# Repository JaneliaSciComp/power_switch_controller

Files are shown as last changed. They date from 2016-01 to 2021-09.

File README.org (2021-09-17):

# Created 2018-07-11 Wed 15:28
#+OPTIONS: title:nil author:nil email:nil toc:t |:t ^:nil
#+OPTIONS: title:nil author:nil email:nil toc:t |:t ^:nil
#+EXPORT_FILE_NAME: README
* Repository Information

- Name :: power_switch_controller
- Version :: 1.0
- License :: BSD, Open-Source Hardware
- URL :: https://github.com/janelia-modular-devices/power_switch_controller.git
- Author :: Peter Polidoro
- Email :: peter@polidoro.io

** Description

This device controls low-side power switches for turning on and off solenoids,
relays, and resistive loads.

* Images

* Usage Instructions

- Connect a power supply to the power switch controller board.
- Connect devices to be switched to the shrouded header connectors on the
  board with either ribbon cables and IDC connectors or individual 2-pin
  connectors.
- Connect USB cable to from device to host machine and control over a serial
  port.

* Build Instructions

- This controller is made from a single 5x3 or 3x2 form factor modular device.
- This device consists of two pcbs, either the (modular_device_base_5x3) and the
  (power_switch_controller_5x3), or the (modular_device_base_3x2) and the
  (power_switch_controller_3x2).
- In addition to the two pcbs, there is one acrylic mounting plate
  (modular_device_enclosure 5x3 enclosure_bottom) or (modular_device_enclosure
  3x2 enclosure_bottom).
- Send the zip files containing the gerbers for each of the two pcbs to your
  favorite pcb manufacturer for fabrication.
- Using the bill of materials and vendor parts lists order the parts necessary
  for construction for the two pcbs and the mounting plate.
- Assemble each of the pcbs using the assembly instructions provided for each.
- Use the dxf file for the enclosure_bottom to cut the mounting plate from the
  acrylic sheet using a laser cutter or send the dxf to a laser cutting
  service for fabrication.

* Hardware

** power_switch_controller_3x2

*** Repository Information

- Name :: power_switch_controller_3x2
- Version :: 1.1
- License :: Open-Source Hardware
- URL :: https://github.com/janelia-kicad/power_switch_controller_3x2
- Author :: Peter Polidoro
- Email :: peter@polidoro.io

**** Description

This board controls up to 8 low-side power switches for turning on and off
solenoids, relays, and resistive loads.

*** Images

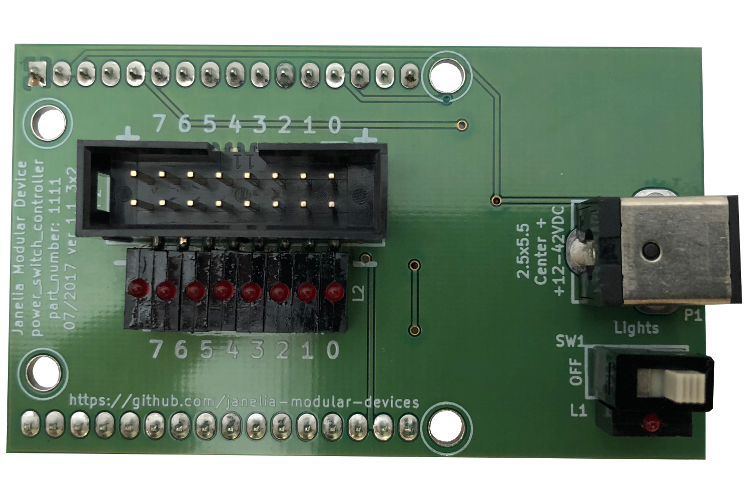
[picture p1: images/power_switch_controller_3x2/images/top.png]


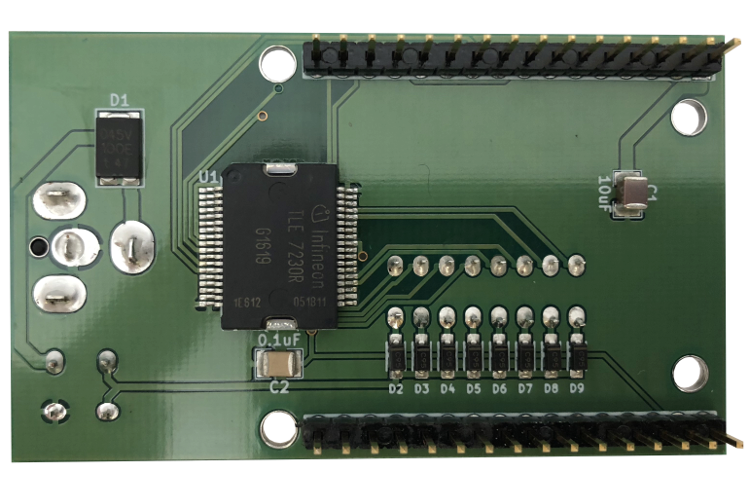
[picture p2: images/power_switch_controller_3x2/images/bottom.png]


*** Schematic

[[file:./hardware/power_switch_controller_3x2/schematic/power_switch_controller_3x2.pdf][./hardware/power_switch_controller_3x2/schematic/power_switch_controller_3x2.pdf]]

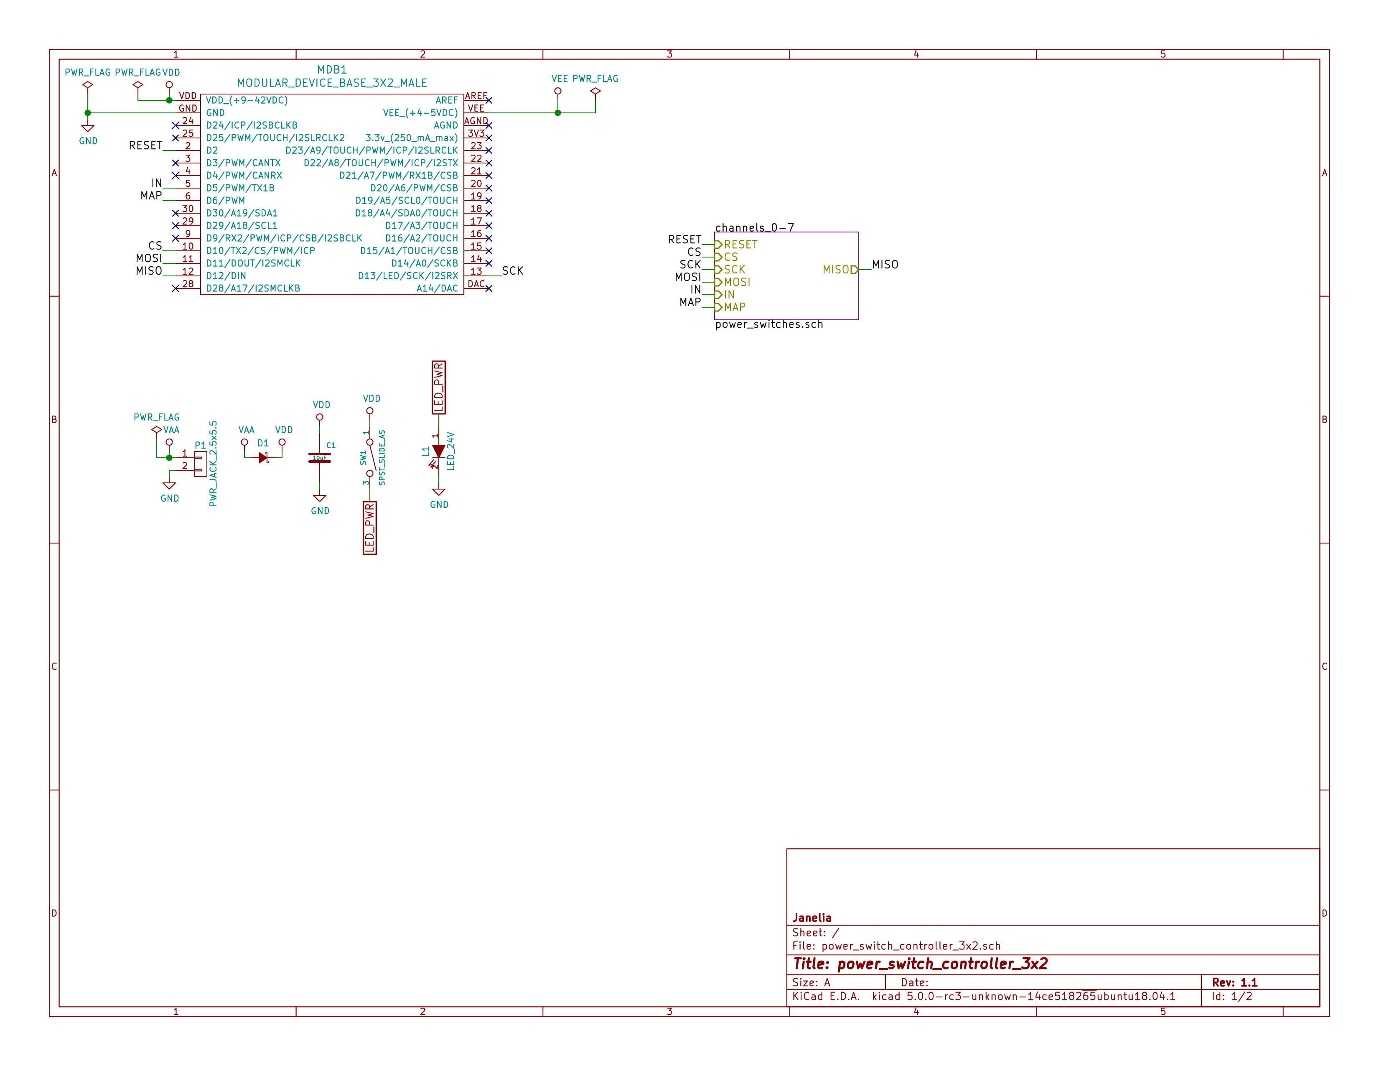
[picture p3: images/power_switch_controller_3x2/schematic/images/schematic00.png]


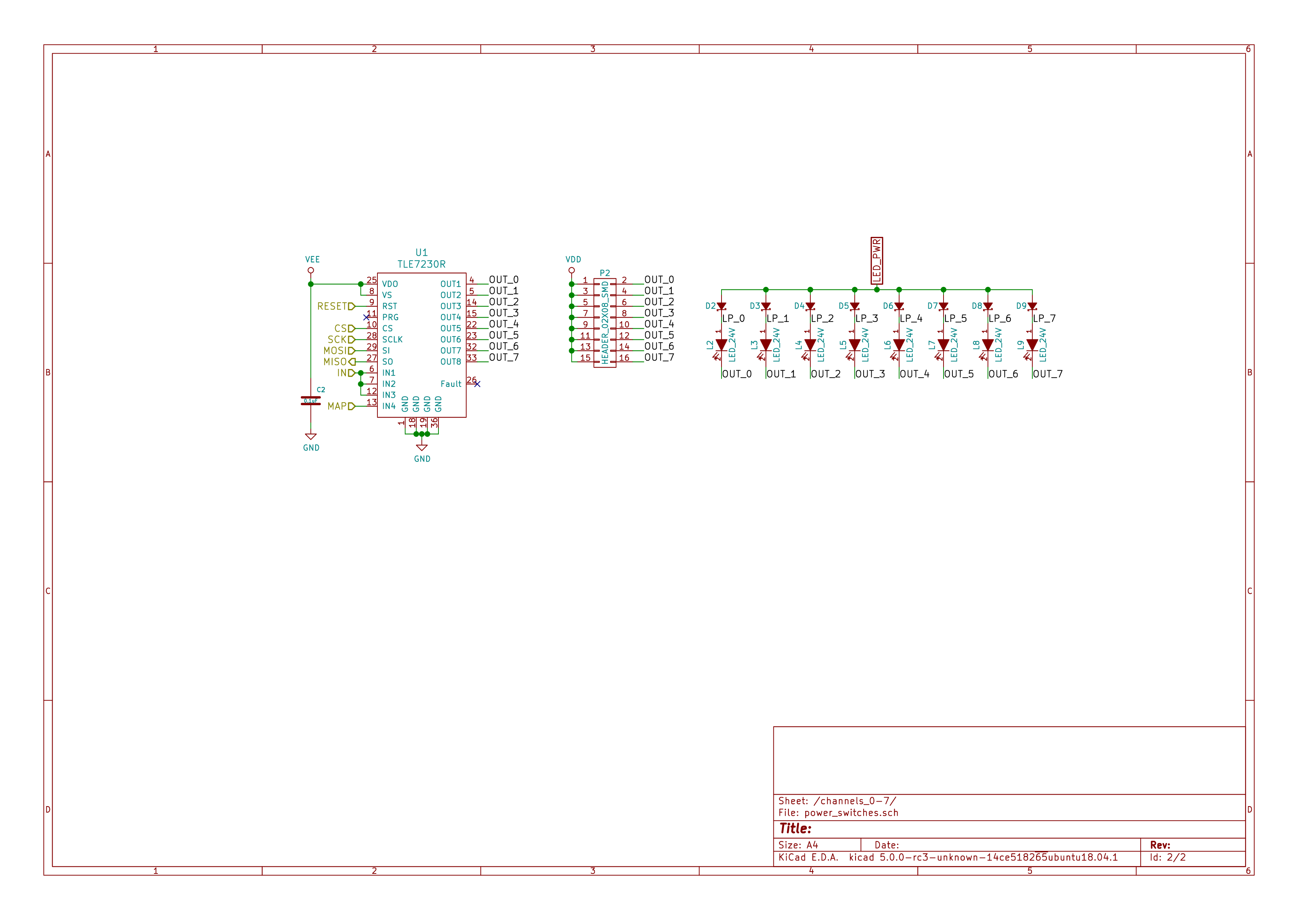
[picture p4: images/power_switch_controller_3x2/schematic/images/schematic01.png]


*** Gerbers

Send gerbers zip file to your favorite PCB manufacturer for fabrication.

[[file:./hardware/power_switch_controller_3x2/gerbers/power_switch_controller_5x3_v1.1.zip][./hardware/power_switch_controller_3x2/gerbers/power_switch_controller_5x3_v1.1.zip]]

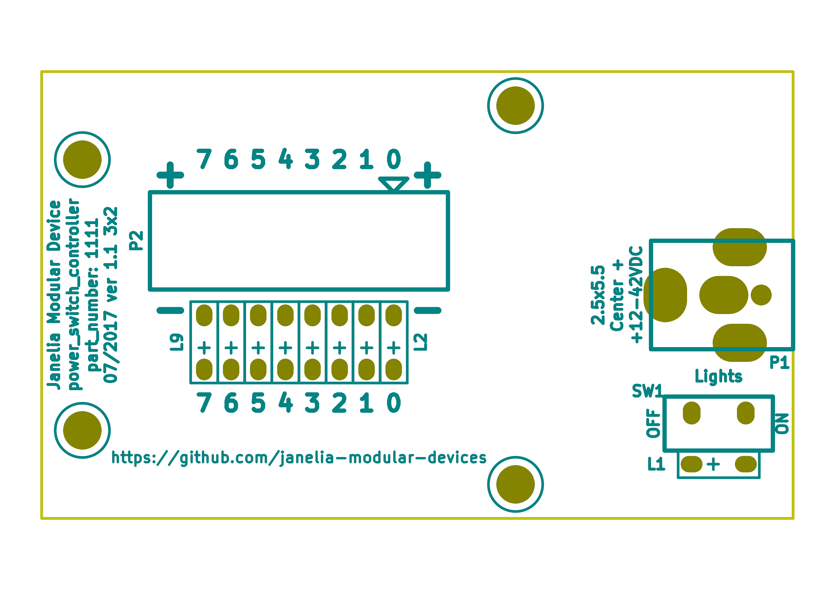
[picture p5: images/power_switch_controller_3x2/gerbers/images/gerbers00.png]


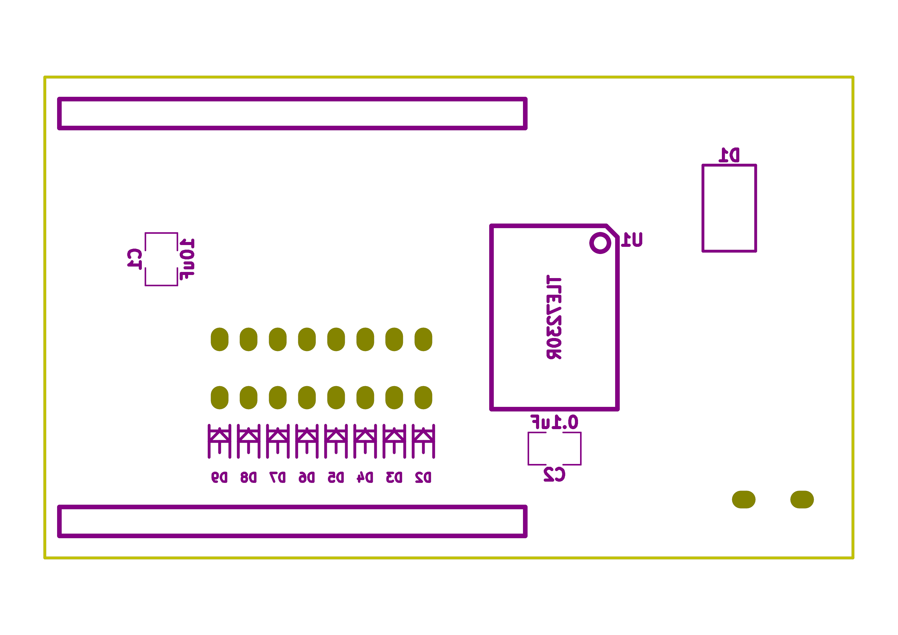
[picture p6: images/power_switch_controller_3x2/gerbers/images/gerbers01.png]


*** Bill of Materials

**** PCB Parts

| Item | Reference(s)               | Quantity | PartNumber     | Vendor  | Description                               |
|------+----------------------------+----------+----------------+---------+-------------------------------------------|
|    1 | C1                         |        1 | 445-4536-1-ND  | digikey | CAP CER 10UF 50V 10% X7S 1210             |
|    2 | C2                         |        1 | 399-13229-1-ND | digikey | CAP CER 0.1UF 100V X7R 1210               |
|    3 | D1                         |        1 | 568-11697-1-ND | digikey | DIODE SCHOTTKY 45V 10A CFP15              |
|    4 | D2 D3 D4 D5 D6 D7 D8 D9    |        8 | CMHD3595 CT-ND | digikey | DIODE GEN PURP 150V 150MA SOD123          |
|    5 | L1 L2 L3 L4 L5 L6 L7 L8 L9 |        9 | 350-1723-ND    | digikey | LED 2MM 24V VERTICAL RED PC MNT           |
|    6 | MDB1                       |        2 | S1011E-16-ND   | digikey | 16 Position Header Through Hole Male Pins |
|    7 | P1                         |        1 | CP-063BH-ND    | digikey | CONN PWR JACK DC 2.5X5.5 8A T/H           |
|    8 | P2                         |        1 | S9187-ND       | digikey | CONN HEADR 2.54MM 16POS GOLD SMD          |
|    9 | SW1                        |        1 | 360-2610-ND    | digikey | SWITCH SLIDE SPST 0.4VA 28V               |
|   10 | U1                         |        1 | TLE7230RCT-ND  | digikey | IC SW SMART OCTAL LOWSIDE PDSO36          |

**** Supplemental Parts

| Item | Quantity | PartNumber   | Vendor  | Description                       |
|------+----------+--------------+---------+-----------------------------------|
|    1 |       32 | WM2800-ND    | digikey | CONN HOUSING 2POS .100 SINGLE     |
|    2 |       64 | WM2512-ND    | digikey | CONN TERM FEMALE 22-24AWG GOLD    |
|    3 |       64 | WM2513-ND    | digikey | CONN TERM FEMALE 24-30AWG GOLD    |
|    4 |        4 | AKC16H-ND    | digikey | CONN IDC SKT 16POS W/POL 15 GOLD  |
|    5 |        1 | MC16M-300-ND | digikey | CBL RIBN 16COND 0.050 MULTI 300ft |
|    6 |        4 | APK16B-ND    | digikey | CONN IDC PIN 16POS 30AU NO LATCH  |
|    7 |       32 | WM2900-ND    | digikey | CONN HOUSING 2POS .100 W/LATCH    |
|    8 |       64 | WM2570-ND    | digikey | CONN TERM FEMALE 22-24AWG GOLD    |
|    9 |       64 | WM2572-ND    | digikey | CONN SOCKET 24-30AWG CRIMP 30AU   |
|   10 |       32 | WM2533-ND    | digikey | CONN HOUSING MALE 2POS .100       |
|   11 |       64 | WM2566-ND    | digikey | CONN PIN 24-30AWG CRIMP 30GOLD    |
|   12 |       64 | WM2567-ND    | digikey | CONN TERM MALE 22-24AWG GOLD      |

**** Vendor Parts Lists

[[file:./hardware/power_switch_controller_3x2/bom/digikey_parts.csv][./hardware/power_switch_controller_3x2/bom/digikey_parts.csv]]

[[file:./hardware/power_switch_controller_3x2/bom/supplemental_digikey_parts.csv][./hardware/power_switch_controller_3x2/bom/supplemental_digikey_parts.csv]]

*** Supplemental Documentation

**** Assembly Instructions

- Solder header pins into the driver board, making note of TOP label.
  Insert header pins on bottom of board so that the long unsoldered header
  pins point down when the TOP label faces up.
- Solder surface mount and through hole components onto the pcb.

** power_switch_controller_5x3

*** Repository Information
- Author :: Peter Polidoro
- License :: Open-Source Hardware

* Firmware

** PowerSwitchController

*** Library Information
- Name :: PowerSwitchController
- Version :: 2.1.3
- License :: BSD
- URL :: https://github.com/janelia-arduino/PowerSwitchController
- Author :: Peter Polidoro
- Email :: peter@polidoro.io

**** Description

Modular device power switch controller library.

*** API NAMES

#+BEGIN_SRC js
  {
    "id": "getApi",
    "result": {
      "firmware": [
        "PowerSwitchController"
      ],
      "verbosity": "NAMES",
      "functions": [
        "setChannelOn",
        "setChannelOff",
        "setChannelsOn",
        "setChannelsOff",
        "toggleChannel",
        "toggleChannels",
        "toggleAllChannels",
        "setAllChannelsOn",
        "setAllChannelsOff",
        "setChannelOnAllOthersOff",
        "setChannelOffAllOthersOn",
        "setChannelsOnAllOthersOff",
        "setChannelsOffAllOthersOn",
        "getChannelsOn",
        "getChannelsOff",
        "getChannelCount",
        "saveState",
        "recallState",
        "addPwm",
        "startPwm",
        "stopPwm",
        "stopAllPwm",
        "setPower",
        "getPowers"
      ],
      "parameters": [
        "channel",
        "channels",
        "state",
        "delay",
        "period",
        "on_duration",
        "count",
        "pwm_index",
        "channel_group",
        "power"
      ],
      "properties": [
        "states"
      ]
    }
  }
#+END_SRC

*** API GENERAL

[[file:./firmware/PowerSwitchController/api/]]

*** Ancestors

[[https://github.com/janelia-arduino/ModularServer]]

[[https://github.com/janelia-arduino/ModularDeviceBase]]

*** Clients

*** Devices

[[https://github.com/janelia-modular-devices/modular_device_base.git]]

[[https://github.com/janelia-modular-devices/power_switch_controller.git]]

*** More Detailed Modular Device Information

[[https://github.com/janelia-modular-devices/modular-devices]]

*** Installation Instructions

[[https://github.com/janelia-arduino/arduino-libraries]]

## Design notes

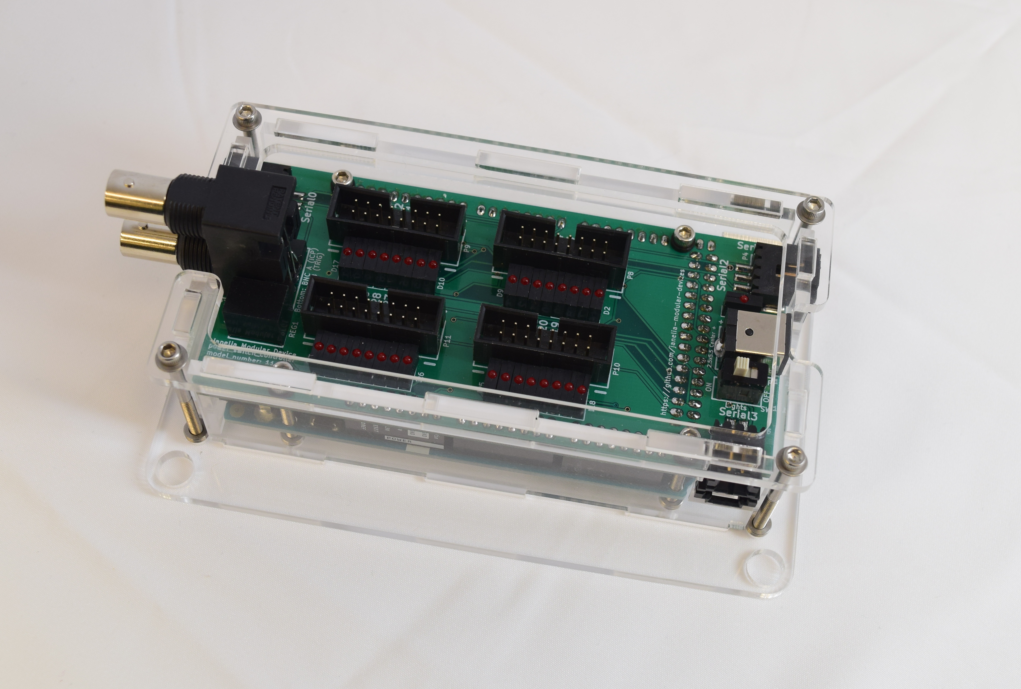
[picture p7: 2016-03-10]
images/power_switch_controller_01.jpg

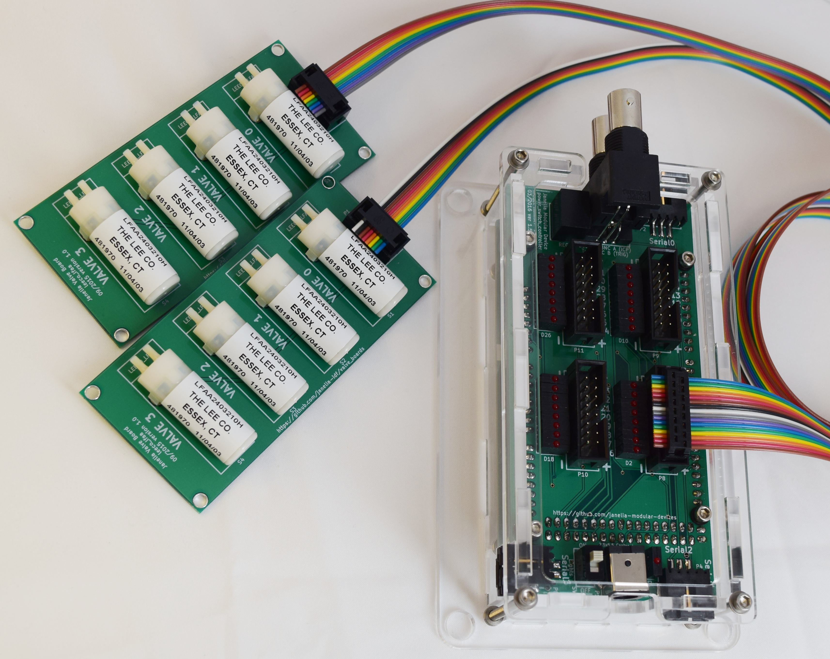
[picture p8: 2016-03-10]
images/power_switch_controller_02.jpg

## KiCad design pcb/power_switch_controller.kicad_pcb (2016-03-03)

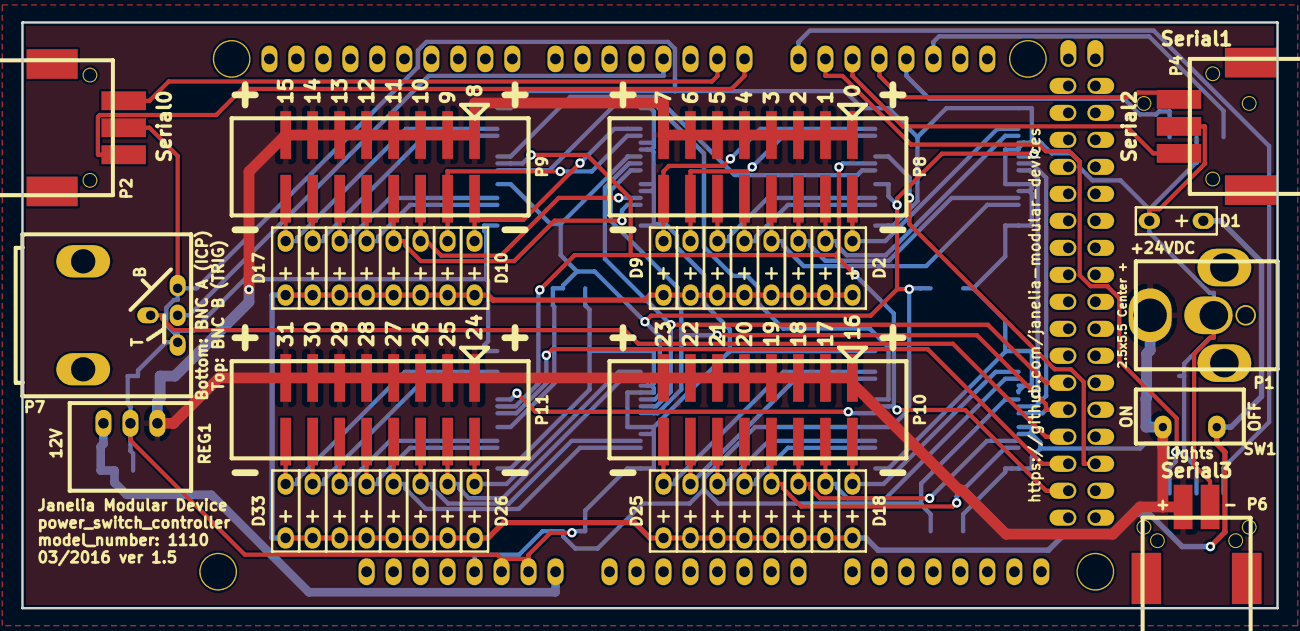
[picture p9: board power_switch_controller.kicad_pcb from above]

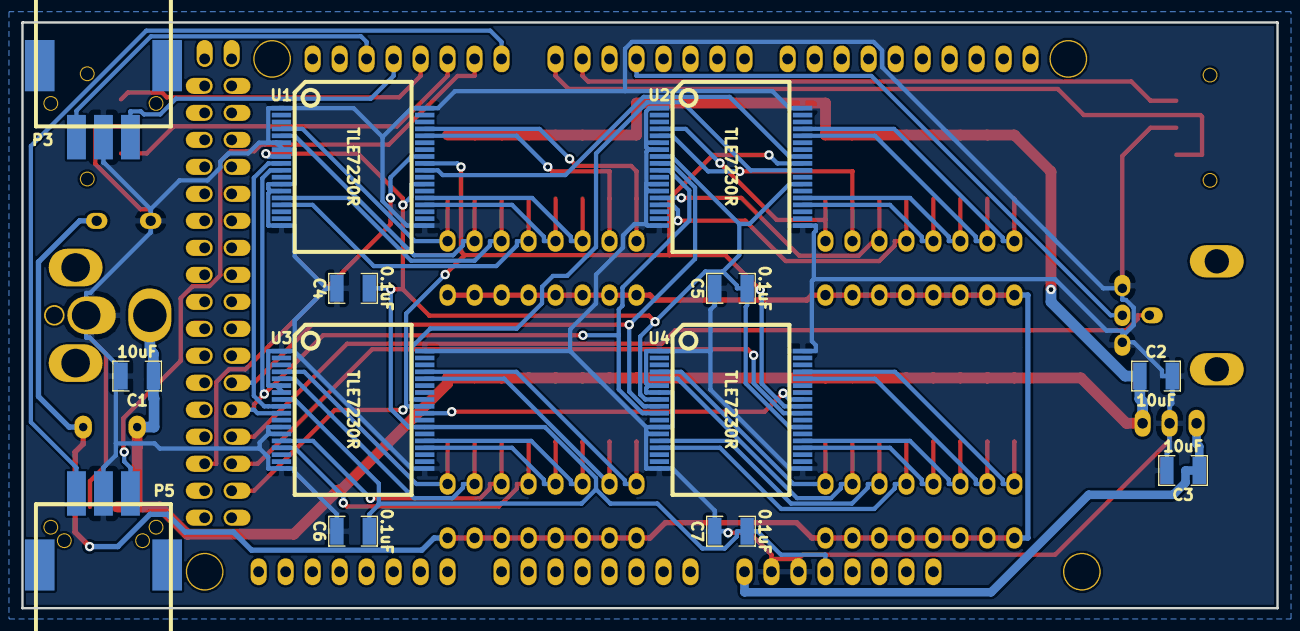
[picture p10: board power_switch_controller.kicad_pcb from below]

Board: 2 copper layers, 118.1 x 55.1 mm, 58 parts (13 on the bottom side), 55 nets.

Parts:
ARDUINO1: ARDUINO_MEGA; ARDUINO_MEGA_SHIELD
C1, C2, C3: 10uF; SM1210
C4, C5, C6, C7: 0.1uF; SM1210
D1, D2, D3, D4, D5, D6, D7, D8, D9, D10, D11, D12, D13, D14, D15, D16, D17, D18, D19, D20, D21, D22, D23, D24, D25, D26, D27, D28, D29, D30, D31, D32, D33: LED_24V; LED_555-3XXX
P1: PWR_JACK_2.5x5.5; DCJACK_2PIN_HIGHCURRENT
P2, P3, P4, P5: HEADER_01X03_SMD_RA; Header_3_Pin_SMD_RA
P6: HEADER_01X02_SMD_RA; Header_2_Pin_SMD_RA
P7: BNC_DOUBLE_RA; BNC_DOUBLE
P8, P9, P10, P11: HEADER_02X08_SMD; HEADER_02x08_SMD
REG1: CONV_DC_DC_12V_1A; DC_DC_CONV_R78C
SW1: SPST_SLIDE_AS
U1, U2, U3, U4: TLE7230R; PG-DSO-36

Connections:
+5V: ARDUINO1.5V_1, C4.1, C5.1, C6.1, C7.1, U1.8, U1.25, U2.8, U2.25, U3.8, U3.25, U4.8, U4.25
/BNC_A: ARDUINO1.48, P7.1
/BNC_B: ARDUINO1.3, P7.3
/CS: ARDUINO1.46, U1.10, U2.10, U3.10, U4.10
/LED_PWR: D1.1, D2.1, D3.1, D4.1, D5.1, D6.1, D7.1, D8.1, D9.1, D10.1, D11.1, D12.1, D13.1, D14.1, D15.1, D16.1, D17.1, D18.1, D19.1, D20.1, D21.1, D22.1, D23.1, D24.1, D25.1, D26.1, D27.1, D28.1, D29.1, D30.1, D31.1, D32.1, D33.1, SW1.3
/MISO: ARDUINO1.50, U4.27
/MOSI: ARDUINO1.51, U1.29
/OUT0: D2.2, P8.2, U1.4
/OUT1: D3.2, P8.4, U1.5
/OUT2: D4.2, P8.6, U1.14
/OUT3: D5.2, P8.8, U1.15
/OUT4: D6.2, P8.10, U1.22
/OUT5: D7.2, P8.12, U1.23
/OUT6: D8.2, P8.14, U1.32
/OUT7: D9.2, P8.16, U1.33
/OUT8: D10.2, P9.2, U2.4
/OUT9: D11.2, P9.4, U2.5
/OUT10: D12.2, P9.6, U2.14
/OUT11: D13.2, P9.8, U2.15
/OUT12: D14.2, P9.10, U2.22
/OUT13: D15.2, P9.12, U2.23
/OUT14: D16.2, P9.14, U2.32
/OUT15: D17.2, P9.16, U2.33
/OUT16: D18.2, P10.2, U3.4
/OUT17: D19.2, P10.4, U3.5
/OUT18: D20.2, P10.6, U3.14
/OUT19: D21.2, P10.8, U3.15
/OUT20: D22.2, P10.10, U3.22
/OUT21: D23.2, P10.12, U3.23
/OUT22: D24.2, P10.14, U3.32
/OUT23: D25.2, P10.16, U3.33
/OUT24: D26.2, P11.2, U4.4
/OUT25: D27.2, P11.4, U4.5
/OUT26: D28.2, P11.6, U4.14
/OUT27: D29.2, P11.8, U4.15
/OUT28: D30.2, P11.10, U4.22
/OUT29: D31.2, P11.12, U4.23
/OUT30: D32.2, P11.14, U4.32
/OUT31: D33.2, P11.16, U4.33
/RESET: ARDUINO1.44, U1.9, U2.9, U3.9, U4.9
/RX0: ARDUINO1.0, P2.1
/RX1: ARDUINO1.19, P3.1
/RX2: ARDUINO1.17, P4.1
/RX3: ARDUINO1.15, P5.1
/SCK: ARDUINO1.52, U1.28, U2.28, U3.28, U4.28
/SO1: U1.27, U2.29
/SO2: U2.27, U3.29
/SO3: U3.27, U4.29
/TX0: ARDUINO1.1, P2.3
/TX1: ARDUINO1.18, P3.3
/TX2: ARDUINO1.16, P4.3
/TX3: ARDUINO1.14, P5.3
/V_IN: ARDUINO1.V_IN, C3.1, REG1.3
GND: ARDUINO1.GND1, ARDUINO1.GND2, C1.2, C2.2, C3.2, C4.2, C5.2, C6.2, C7.2, D1.2, P1.2, P2.2, P3.2, P4.2, P5.2, P6.1, P7.2, P7.4, REG1.2, U1.1, U1.6, U1.7, U1.12, U1.13, U1.18, U1.19, U1.36, U2.1, U2.6, U2.7, U2.12, U2.13, U2.18, U2.19, U2.36, U3.1, U3.6, U3.7, U3.12, U3.13, U3.18, U3.19, U3.36, U4.1, U4.6, U4.7, U4.12, U4.13, U4.18, U4.19, U4.36
VAA: C1.1, C2.1, P1.1, P6.2, P8.1, P8.3, P8.5, P8.7, P8.9, P8.11, P8.13, P8.15, P9.1, P9.3, P9.5, P9.7, P9.9, P9.11, P9.13, P9.15, P10.1, P10.3, P10.5, P10.7, P10.9, P10.11, P10.13, P10.15, P11.1, P11.3, P11.5, P11.7, P11.9, P11.11, P11.13, P11.15, REG1.1, SW1.1

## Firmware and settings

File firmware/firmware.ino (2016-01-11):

// power_switch_controller
#include "Flash.h"
#include <EEPROM.h>
#include "Streaming.h"
#include "ArduinoJson.h"
#include "JsonSanitizer.h"
#include "JsonStream.h"
#include "Array.h"
#include "Vector.h"
#include "MemoryFree.h"
#include "ConstantVariable.h"
#include "SavedVariable.h"
#include "BetterMap.h"
#include "ModularServer.h"
#include "NewhavenDisplay.h"
#include "Encoder.h"
#include "StandaloneInterface.h"
#include "EventController.h"
#include "Constants.h"
#include "Callbacks.h"
#include "Controller.h"

#include "SPI.h"
#include "PowerSwitch.h"
#include "IndexedContainer.h"


// See README.md for more information

void setup()
{
  controller.setup();
}

void loop()
{
  controller.update();
}

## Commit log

2014-11-25 Pcb file setup.
    [power_switch_controller.sch]
2014-12-12 Initial design setup.
    [bom_pcb_add.csv, digikey_order_pcb_add.csv, power_switch_controller.dsn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]
2015-01-05 Made design changes preparing for version 1.0.
    [power_switch_controller.dsn, power_switch_controller.kicad_pcb, power_switch_controller.sch]
2015-01-06 Changed connectors to 2x16 header.
    [power_switch_controller.kicad_pcb, power_switch_controller.sch]
2015-01-08 Moved components on pcb.
    [power_switch_controller.dsn, power_switch_controller.kicad_pcb, power_switch_controller.sch]
2015-01-08 Finished pcb version 1.0
    [bom_pcb.csv, bom_pcb_add.csv, digikey_order.csv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]
2015-01-09 Added schematic pdf.
2015-01-09 Added schematic svg.
2015-01-16 Progress on firmware for pcb v1.0.
2015-01-20 Progress towards 32 power switches.
    [power_switch_controller.kicad_pcb, power_switch_controller.sch]
2015-01-21 Finished pcb v1.1.
    [bom_pcb.csv, bom_pcb_add.csv, digikey_order.csv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]
2015-01-28 remote -> modular.
    [power_switch_controller.kicad_pcb]
2015-02-06 Moved modular_device setup into power_switch_controller.
2015-02-13 Added more StandAlone frames.
2015-02-18 pcb v1.2.
    [power_switch_controller.dsn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]
2015-03-19 StandardCplusplus -> array. Updated pin constants.
2015-04-18 Added new frames.
2015-04-22 Added spikeHold standalone frame.
2015-04-22 Partially updated pwm frame.
2015-04-22 Finished pwm standalone frame.
2015-07-13 JaneliaSciComp -> janelia-modular-devices.
    [power_switch_controller.kicad_pcb]
2015-08-10 SPST switch -> DPST switch.
    [bom_pcb.csv, bom_pcb_add.csv, digikey_order_pcb.csv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]
2015-08-10 Updated digikey_order_add.
    [digikey_order_pcb_add.csv, power_switch_controller.kicad_pcb]
2015-09-09 led_pwr_pin -> lights_pin.
2015-09-09 Kicad update.
    [power_switch_controller.sch]
2015-10-02 New digikey order for multiple modular devices.
    [digikey_order.csv]
2016-01-11 Made some changes, but not working at this commit.
    [firmware.ino]
2016-02-24 Progress towards pcb v1.4.
    [power_switch_controller.kicad_pcb, power_switch_controller.sch]
2016-02-26 Updated bom.
    [bom_pcb.csv, bom_pcb_add.csv, digikey_order_pcb.csv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]
2016-02-29 Added TLE5X.
    [power_switch_controller.kicad_pcb]
2016-03-03 Finished pcb v1.5.
    [power_switch_controller-B.Cu.gbl, power_switch_controller-B.Mask.gbs, power_switch_controller-B.SilkS.gbo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]
2016-03-03 Updated discontinued part.
    [bom_pcb.csv, digikey_order.csv, digikey_order_pcb.csv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]
2016-03-09 Separated standalone firmware from device firmware.
2016-06-21 Create mega pcb.
    [bom_pcb.csv, bom_pcb_add.csv, digikey_order.csv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]
2016-06-21 Progress towards mega pcb 1.6.
    [power_switch_controller_mega.dsn, power_switch_controller_mega.kicad_pcb, power_switch_controller_mega.sch]
2016-06-22 Finished pcb 1.6.
    [bom_pcb.csv, digikey_order.csv, digikey_order_pcb.csv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]
2016-06-23 Updated Arduino Mega digikey part number.
    [bom_pcb.csv, digikey_order.csv, digikey_order_pcb.csv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]
2016-07-13 Progess towards mega pcb1.7.
    [bom_pcb.csv, digikey_order_pcb.csv, power_switch_controller_mega.kicad_pcb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]
2016-07-15 Modified text size.
    [power_switch_controller_mega.kicad_pcb]
2016-07-18 Changed power supply.
    [bom_pcb_add.csv, digikey_order_pcb_add.csv]
2016-07-18 Initial add of pcb/teensy.
    [bom_pcb.csv, bom_pcb_add.csv, digikey_order.csv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]
2016-07-18 Progress towards teensy v1.0.
    [power_switch_controller_teensy.sch]
2016-07-20 More progress towards v1.0.
    [power_switch_controller_teensy.kicad_pcb, power_switch_controller_teensy.sch]
2016-07-25 Finished teensy pcb v1.0.
    [bom_pcb.csv, bom_pcb_add.csv, digikey_order.csv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]
2016-08-09 Removed obsolete footprint.
2016-08-17 Modified firmware to work with teensy hardware.
2016-09-21 pcb -> hardware.
    [bom_pcb.csv, bom_pcb_add.csv, digikey_order.csv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]
2016-12-14 Updated firmware/PowerSwitchController.
2017-08-08 Removed old hardware files.
    [bom_pcb.csv, bom_pcb_add.csv, digikey_order.csv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]
